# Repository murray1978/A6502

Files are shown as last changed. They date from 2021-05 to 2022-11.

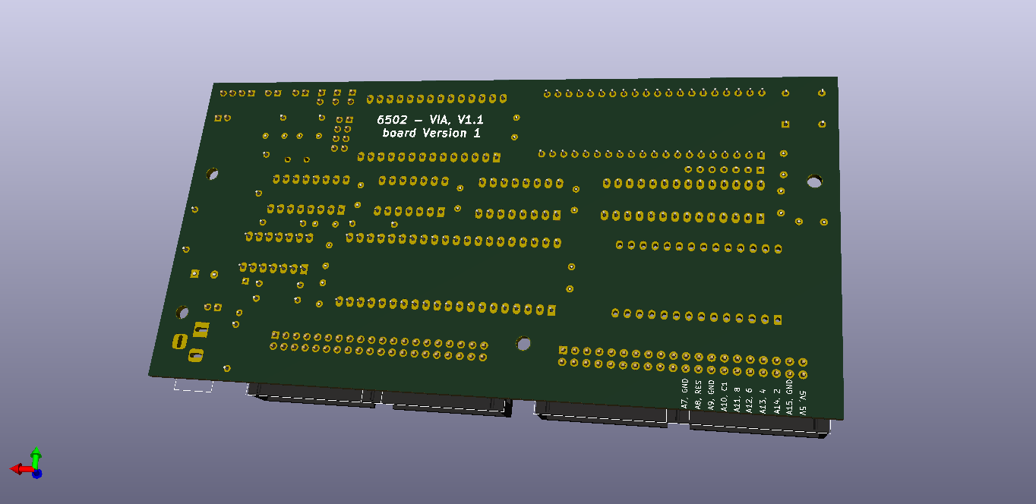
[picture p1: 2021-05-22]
Hardware/6502 V3/6502-Controller1.1.png

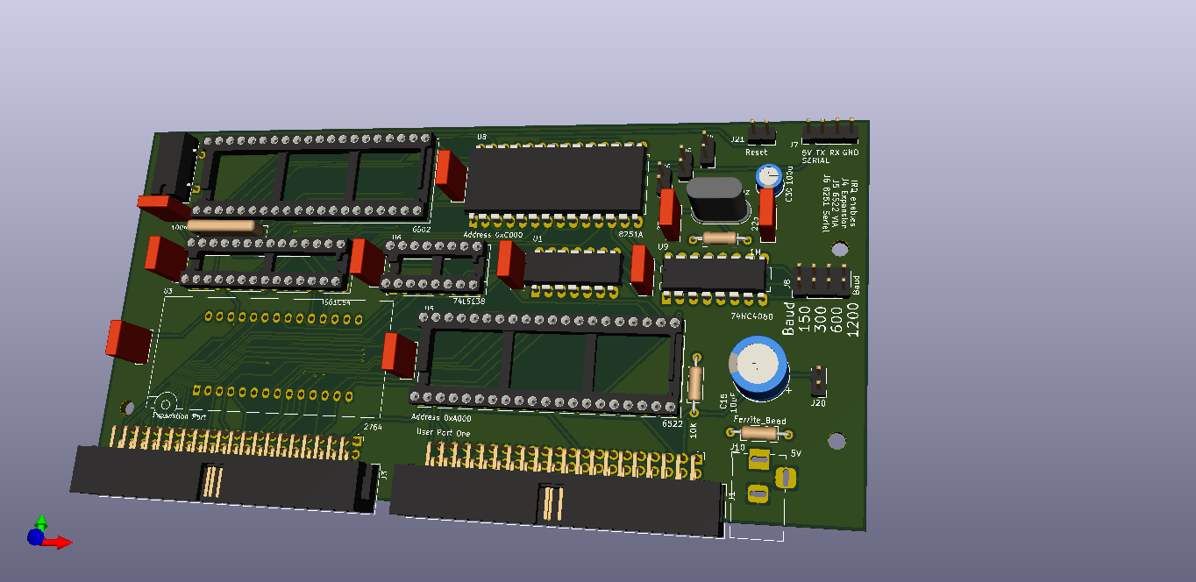
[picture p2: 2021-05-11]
Hardware/6502 V3/6502-Controller.png

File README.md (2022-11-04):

# A6502
- 6502 project running a modified wozmon and wozaci.
- As it stands ram, rom, 8251 interfaces work, yet to try the 6522 interface, the aci or loading basic from the aci.
- ACI will not work unless you remove the rom, make a daughter board for it with 4K of ram, a connector for the ACI 
  and have the rom selected from address 0xF000h, the ram from 0xE000h, and the ACI at the default 0xC000h as the current
  memory decodes the ROM at 0xE000h.
  
 ## version 2 update.
- 11/10/21 Currently the board uses a modified version of EWoz 1.0 (Not uploaded yet)
- 14/8/21 version 2 is included as /hardware/6502/6502-Controller.pro /hardware/6502/6502-Controller.sch and /hardware/6502/6502-Controller.kicad_pcb.
- Fixed an issue with R2 not having a 5V supply, R2 is part of the reset circuit.
- ~The firmware is 6502mon.asm and 6502aci.asm both have yet to be run.
- ~You may have to play around with the 8251a setup for it to work.
### Backplane 
 - Version 1 of the backplane in progress.

 ## Improvements
 - Any improvements and suggestions are welcome

 ## Errors
  ### For the serial to work
   - Select the 150 jumper for 2400 baud, place a jumper between pin 22 and 24 of the 8251, this connects DTR and DSR.
   - Other baud rates should work

 ## Specs
- 6502 processor at 1Mhz
- 8Kb Ram, IS61C64 start 0x0000
- 8Kb Rom, 28C64 start 0xE000
 One user port via a 6522 at 0xA000
 Serial port via a 8251 at 0x8000, baud rates 2400, 1200, 600, and 300
 
 ## Source
 Current source is for the v2.0 board, 
 
 ### Assembling the source
 Currently I am using asm80.com to assemble the code (downloads as a 64k file ) then a hex editor to trim the last 0x2000 bytes (8k)
 And finaly "burning" the eeprom with the 8k image.

 ## Hardware
 Current board is 6502-Controller.kicad_pcb now version 2

 ### Component Selection
 Mostly 74LS, 74HC support chips, 74HCT may also work.

 ## Issues for 6502.1.1.kicad_pcb
 1.  8251A may require a seperate clock if cpu is at 1mhz and programmed at x64 rate.
 2.  No power light 
 3.  Reset could damage older chips, do not use as is. Replace 100u reset cap with 100n cap.
 4.  8251a reset is active high, not low as shown on board.
 5.  74hc4060 incorrect pinout, leading to misleading baud rate signals.

 ## Changes from 6502.1.1.kicad_pcb to 6502-Controller.kicad_pcb
 - ~Add Clock for 8251A, cannot use procssor clock as the 8251A requires a clock atleast 30 times the baud rate. 
 -  CPU clock works with 8251 ok.
 - ~Add LED Power indicator 
 - [x]  Add/Fix missing silk screen text for, user and expasion ports, U4 etc 
 - [x]  Change pinout for RN1, add a pin. 
 -  ~Redesign baud rate generator? make it smaller? Use x1 or x16 for baud rate selection.~
 - [x]  Move bypass caps for ease of extraction tool access. 
 - ~Change values of Baudrate text, reflect 64x clock speed (see issue 5)~
 - ~Reset, change the basic r/c reset to a 555 or inverter based reset, or 100n cap instead of 100u. 
 - [x]  74hc4060 pin out has to be updated, 

## Future additions

 - Basic, looking at adding a basic ROM at 0xA000, 8Kb https://
 - FDC at 0x23F0 (via isa adapter and 82077 FDC controller)
 - An LCD 2x16 Display or CRT monitor.
 
 ## Version 3 idea's
  - Redesign main board as a edge card including address, data and control bus buffers, retaining Serial I/O
  - Have I/O take up a small chunk of memory, from 0xC000 to 0xE000
  - Backplane with 5V PSU
  - Basic in EPROM, bank switched, monitor code moved down to low memory, (BBC Micro like)

## Code Snippets
### Memory Check/count, from MS Basic

        lda     #<RAMSTART2
        ldy     #>RAMSTART2
        sta     LINNUM
        sty     LINNUM+1
        ldy     #$00
L40D7:
        inc     LINNUM
        bne     L40DD
        inc     LINNUM+1
L40DD:
        lda     #$92 ; 10010010 / 00100100
        sta     (LINNUM),y
        cmp     (LINNUM),y
        bne     L40FA
        asl     a
        sta     (LINNUM),y
        cmp     (LINNUM),y
        beq     L40D7; old: faster
        bne     L40FA
L40EE:
        jsr     CHRGOT
        jsr     LINGET
        tay
        beq     L40FA
        jmp     SYNERR
L40FA:

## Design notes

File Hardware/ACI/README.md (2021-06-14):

## Current aci issues.
- eprom footprint wrong.
- bypass caps wrong value, use 100n
- 3.5mm sockets to far from edge.
- text on silkscreen a bit hard to read for some values.
- yet to find any more mistakes.

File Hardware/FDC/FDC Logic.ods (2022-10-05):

 | INPUTS |  |  |  | OUTPUTS
(WD_A0) | (WD_DOR) | (WD_DCR) | (WD_CS)
A0 | A1 | A2 | CS |  | _A0 | _CS | _DOR | _DCR
0 | 0 | 0 | 1 | No Chip Select | 0 | 1 | 1 | 1
0 | 0 | 1 | 0 | DCR Select | 0 | 0 | 1 | 0
0 | 0 | 1 | 1 | No Chip Select | 0 | 1 | 1 | 1
0 | 1 | 0 | 0 | DOR Select | 0 | 0 | 0 | 1
0 | 1 | 0 | 1 | No Chip Select | 0 | 1 | 1 | 1
0 | 1 | 1 | 0 | In Valid | 0 | 1 | 1 | 1
0 | 1 | 1 | 1 | No Chip Select | 0 | 1 | 1 | 1
1 | 0 | 0 | 0 | A0 Select | 1 | 0 | 1 | 1
1 | 0 | 0 | 1 | No Chip Select | 0 | 1 | 1 | 1
1 | 0 | 1 | 0 | In Valid | 0 | 1 | 1 | 1
1 | 0 | 1 | 1 | No Chip Select | 0 | 1 | 1 | 1
1 | 1 | 0 | 0 | In Valid | 0 | 1 | 1 | 1
1 | 1 | 0 | 1 | No Chip Select | 0 | 1 | 1 | 1
1 | 1 | 1 | 0 | InValid | 0 | 1 | 1 | 1
1 | 1 | 1 | 1 | No Chip Select | 0 | 1 | 1 | 1
Notes:
Could use clock

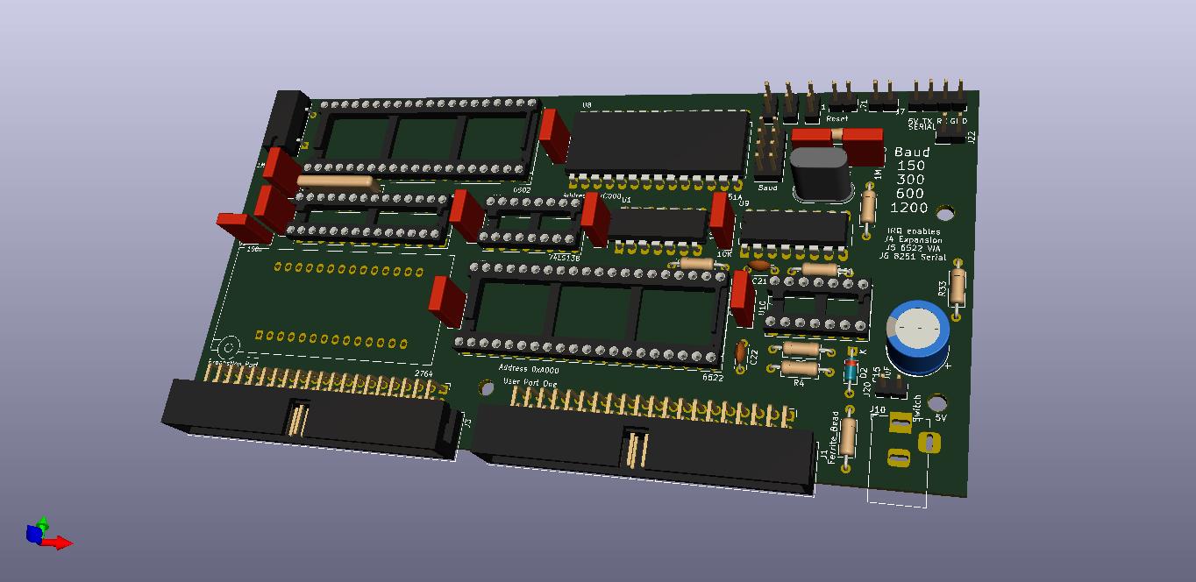
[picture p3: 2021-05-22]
Hardware/6502 V3/6502-Controller1.2.jpg

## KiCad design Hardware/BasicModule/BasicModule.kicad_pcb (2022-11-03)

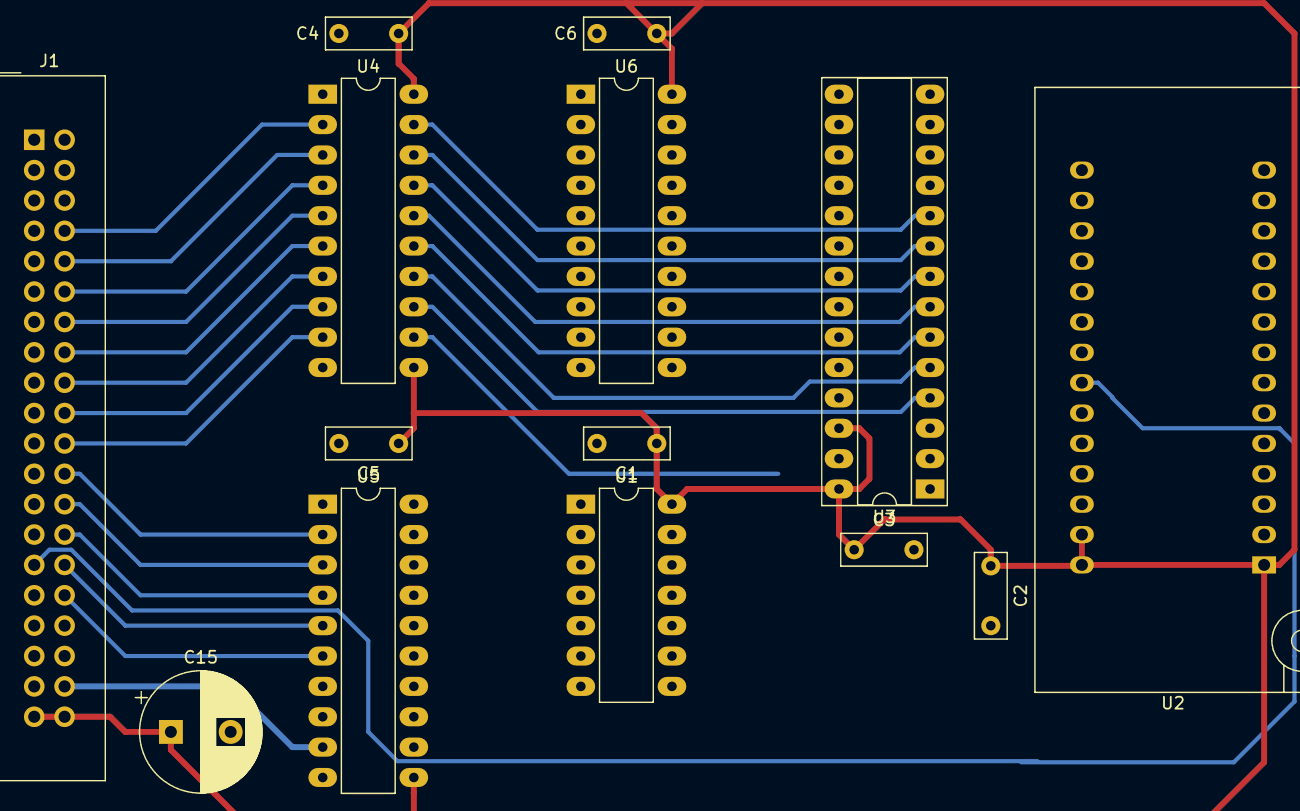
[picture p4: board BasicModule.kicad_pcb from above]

Board: 2 copper layers, 14 parts (0 on the bottom side), 48 nets.

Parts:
C1, C2, C3, C4, C5, C6: 100n; C_Rect_L7.0mm_W2.5mm_P5.00mm
C15: 10uF; CP_Radial_D10.0mm_P5.00mm
J1: Expanstion Port; IDC-Header_2x20_P2.54mm_Vertical
U1: 74LS04; DIP-14_W7.62mm_LongPads
U2: 2764; DIP_Socket-28_W11.9_W12.7_W15.24_W17.78_W18.5_3M_228-1277-0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
U3: IS61C64; DIP-28_W7.62mm_Socket_LongPads
U4, U5: 74LS573; DIP-20_W7.62mm_LongPads
U6: 74LS245; DIP-20_W7.62mm_LongPads

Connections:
0x2000: J1.35, U3.20
0xC000: J1.29, U2.22
5V: C1.1, C2.1, C3.1, C4.1, C5.1, C6.1, C15.1, J1.39, J1.40, U1.14, U2.1, U2.27, U2.28, U3.26, U3.28, U4.11, U4.20, U5.11, U5.20, U6.20
/A0: U2.10, U3.10, U4.19
/A0_1: J1.8, U4.2
/A1: U2.9, U3.9, U4.18
/A1_1: J1.10, U4.3
/A2: U2.8, U3.8, U4.17
/A2_1: J1.12, U4.4
/A3: U2.7, U3.7, U4.16
/A3_1: J1.14, U4.5
/A4: U2.6, U3.6, U4.15
/A4_1: J1.16, U4.6
/A5: U2.5, U3.5, U4.14
/A5_1: J1.18, U4.7
/A6: U2.4, U3.4, U4.13
/A6_1: J1.20, U4.8
/A7: U2.3, U3.3, U4.12
/A7_1: J1.22, U4.9
/A8: U2.25, U3.25, U5.19
/A8_1: J1.24, U5.2
/A9: U2.24, U3.24, U5.18
/A9_1: J1.26, U5.3
/A10: U2.21, U3.21, U5.17
/A10_1: J1.28, U5.4
/A11: U2.23, U3.23, U5.16
/A11_1: J1.30, U5.5
/A12: U2.2, U3.2, U5.15
/A12_1: J1.32, U5.6
/D0: U2.11, U3.11, U6.18
/D0_1: J1.3, U6.2
/D1: U2.12, U3.12, U6.17
/D1_1: J1.5, U6.3
/D2: U2.13, U3.13, U6.16
/D2_1: J1.7, U6.4
/D3: U2.15, U3.15, U6.15
/D3_1: J1.9, U6.5
/D4: U2.16, U3.16, U6.14
/D4_1: J1.11, U6.6
/D5: U2.17, U3.17, U6.13
/D5_1: J1.13, U6.7
/D6: U2.18, U3.18, U6.12
/D6_1: J1.15, U6.8
/D7: U2.19, U3.19, U6.11
/D7_1: J1.17, U6.9
GND: C1.2, C2.2, C3.2, C4.2, C5.2, C6.2, C15.2, J1.1, J1.2, J1.21, J1.25, J1.37, U1.7, U2.14, U2.20, U3.14, U3.22, U4.1, U4.10, U5.1, U5.10, U6.10, U6.19
R~W: J1.19, U1.5, U3.27
~Read: U1.6, U6.1

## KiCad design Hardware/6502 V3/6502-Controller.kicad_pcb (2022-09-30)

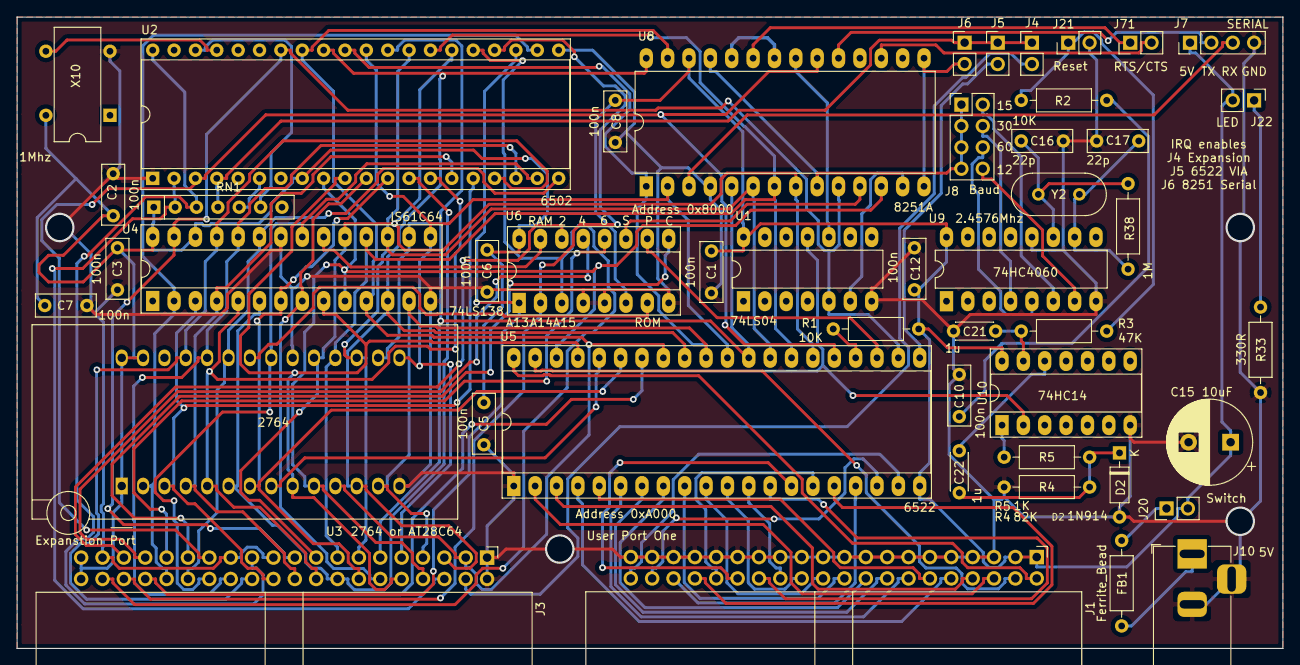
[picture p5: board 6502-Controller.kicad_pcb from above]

Board: 2 copper layers, 150.5 x 75.1 mm, 47 parts (0 on the bottom side), 87 nets.

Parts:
C1, C2, C3, C5, C6, C7, C8, C10, C12: 100n; C_Rect_L7.0mm_W2.5mm_P5.00mm
C15: 10uF; CP_Radial_D10.0mm_P5.00mm
C16, C17: 22p; C_Rect_L7.0mm_W2.5mm_P5.00mm
C21, C22: 1u; C_Disc_D4.3mm_W1.9mm_P5.00mm
D2: 1N914; D_DO-35_SOD27_P7.62mm_Horizontal
FB1: Ferrite_Bead; R_Axial_DIN0207_L6.3mm_D2.5mm_P10.16mm_Horizontal
J1: User Port One; IDC-Header_2x20_P2.54mm_Horizontal
J3: Expanstion Port; IDC-Header_2x20_P2.54mm_Horizontal
J4: Expansion IRQ Enable; PinHeader_1x02_P2.54mm_Vertical
J5: 6522 IRQ Enable; PinHeader_1x02_P2.54mm_Vertical
J6: SERIAL IRQ Enale; PinHeader_1x02_P2.54mm_Vertical
J7: SERIAL; PinHeader_1x04_P2.54mm_Vertical
J8: Baud; PinHeader_2x04_P2.54mm_Vertical
J10: 5V; BarrelJack_Horizontal
J20: Switch; PinHeader_1x02_P2.54mm_Vertical
J21: Reset; PinHeader_1x02_P2.54mm_Vertical
J22: LED; PinHeader_1x02_P2.54mm_Vertical
J71: RTS/CTS; PinHeader_1x02_P2.54mm_Vertical
R1, R2: 10K; R_Axial_DIN0207_L6.3mm_D2.5mm_P10.16mm_Horizontal
R3: 47K; R_Axial_DIN0207_L6.3mm_D2.5mm_P10.16mm_Horizontal
R4: 82K; R_Axial_DIN0207_L6.3mm_D2.5mm_P10.16mm_Horizontal
R5: 1K; R_Axial_DIN0207_L6.3mm_D2.5mm_P10.16mm_Horizontal
R33: 330R; R_Axial_DIN0207_L6.3mm_D2.5mm_P10.16mm_Horizontal
R38: 1M; R_Axial_DIN0207_L6.3mm_D2.5mm_P10.16mm_Horizontal
RN1: 10K; R_Array_SIP7
U1: 74LS04; DIP-14_W7.62mm_LongPads
U2: 6502; DIP-40_W15.24mm_Socket
U3: 2764; DIP_Socket-28_W11.9_W12.7_W15.24_W17.78_W18.5_3M_228-1277-0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
U4: IS61C64; DIP-28_W7.62mm_Socket_LongPads
U5: 6522; DIP-40_W15.24mm_Socket_LongPads
U6: 74LS138; DIP-16_W7.62mm_Socket_LongPads
U8: 8251A; DIP-28_W15.24mm_LongPads
U9: 74HC4060; DIP-16_W7.62mm_LongPads
U10: 74HC14; DIP-14_W7.62mm_Socket_LongPads
X10: SG-531; Oscillator_SeikoEpson_SG-8002DC
Y2: 2.4576Mhz; Crystal_HC49-U_Vertical

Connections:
0x2000: J3.35, U6.14
0x4000: J3.33, U6.13
0x6000: J3.31, U6.12
0xC000: J3.29, U6.9
5V: C1.1, C2.1, C3.1, C5.1, C6.1, C7.1, C8.1, C10.1, C12.1, C15.1, J1.1, J1.3, J3.39, J3.40, J7.1, J20.2, J22.2, R1.2, R2.1, RN1.1, U1.14, U2.8, U3.1, U3.27, U3.28, U4.26, U4.28, U5.20, U6.6, U6.16, U8.26, U9.16, U10.14, X10.8
/A0: J3.8, U2.9, U3.10, U4.10, U5.38, U8.12
/A1: J3.10, U2.10, U3.9, U4.9, U5.37
/A2: J3.12, U2.11, U3.8, U4.8, U5.36
/A3: J3.14, U2.12, U3.7, U4.7, U5.35
/A4: J3.16, U2.13, U3.6, U4.6
/A5: J3.18, U2.14, U3.5, U4.5
/A6: J3.20, U2.15, U3.4, U4.4
/A7: J3.22, U2.16, U3.3, U4.3
/A8: J3.24, U2.17, U3.25, U4.25
/A9: J3.26, U2.18, U3.24, U4.24
/A10: J3.28, U2.19, U3.21, U4.21
/A11: J3.30, U2.20, U3.23, U4.23
/A12: J3.32, U2.22, U3.2, U4.2
/A13: J3.34, U2.23, U6.1
/A14: J3.36, U2.24, U6.2
/A15: J3.38, U2.25, U6.3
/CA1: J1.2, U5.40
/CA2: J1.4, U5.39
/CB1: J1.38, U5.18
/CB2: J1.40, U5.19
/D0: J3.3, U2.33, U3.11, U4.11, U5.33, U8.27
/D1: J3.5, U2.32, U3.12, U4.12, U5.32, U8.28
/D2: J3.7, U2.31, U3.13, U4.13, U5.31, U8.1
/D3: J3.9, U2.30, U3.15, U4.15, U5.30, U8.2
/D4: J3.11, U2.29, U3.16, U4.16, U5.29, U8.5
/D5: J3.13, U2.28, U3.17, U4.17, U5.28, U8.6
/D6: J3.15, U2.27, U3.18, U4.18, U5.27, U8.7
/D7: J3.17, U2.26, U3.19, U4.19, U5.26, U8.8
/PA0: J1.6, U5.2
/PA1: J1.8, U5.3
/PA2: J1.10, U5.4
/PA3: J1.12, U5.5
/PA4: J1.14, U5.6
/PA5: J1.16, U5.7
/PA6: J1.18, U5.8
/PA7: J1.20, U5.9
/PB0: J1.22, U5.10
/PB1: J1.24, U5.11
/PB2: J1.26, U5.12
/PB3: J1.28, U5.13
/PB4: J1.30, U5.14
/PB5: J1.32, U5.15
/PB6: J1.34, U5.16
/PB7: J1.36, U5.17
B150: J8.2, U9.6
B300: J8.4, U9.4
B600: J8.6, U9.5
B1200: J8.8, U9.7
CLK0: U2.37, X10.5
CLK1: J3.27, U2.3, U5.25, U8.20
GND: C1.2, C2.2, C3.2, C5.2, C6.2, C7.2, C8.2, C10.2, C12.2, C15.2, C16.2, C17.2, C21.2, D2.2, J1.5, J1.7, J1.9, J1.11, J1.13, J1.15, J1.17, J1.19, J1.21, J1.23, J1.25, J1.27, J1.29, J1.31, J1.33, J1.35, J1.37, J1.39, J3.1, J3.2, J3.21, J3.25, J3.37, J7.4, J10.2, J10.3, J21.2, R4.2, R33.1, U1.7, U2.1, U2.21, U3.14, U3.20, U4.14, U4.22, U5.1, U6.4, U6.5, U6.8, U8.4, U9.8, U9.12, U10.7, X10.4
unnamed: C16.1, R38.2, U9.11, Y2.1
unnamed: C17.1, R38.1, U9.10, Y2.2
unnamed: C21.1, R3.2, U10.13
unnamed: C22.1, U10.12
unnamed: C22.2, D2.1, R4.1, R5.1
unnamed: FB1.1, J20.1
unnamed: FB1.2, J10.1
unnamed: J3.4, J4.2
unnamed: J5.2, U5.21
unnamed: J6.2, U8.14, U8.15
unnamed: J7.2, U8.19
unnamed: J7.3, U8.3
unnamed: J8.1, J8.3, J8.5, J8.7, U8.9, U8.25
unnamed: J21.1, R2.2, R3.1
unnamed: J22.1, R33.2
unnamed: J71.1, U8.23
unnamed: J71.2, U8.17
unnamed: R1.1, U5.24
unnamed: R5.2, U10.1
unnamed: RN1.5, U2.6
unnamed: RN1.6, U2.38
unnamed: U1.10, U8.21
RDY: J3.6, RN1.2, U2.2
R~W: J3.19, U1.5, U2.34, U4.27, U5.22, U8.10
~6522_EN: U5.23, U6.10
~8251_EN: U6.11, U8.11
~IRQ: J4.1, J5.1, J6.1, RN1.4, U2.4
~RAM_EN: U4.20, U6.15
~RES: J3.23, RN1.3, U1.11, U2.40, U5.34, U10.2
~ROM_EN: U3.22, U6.7
~Read: U1.6, U8.13

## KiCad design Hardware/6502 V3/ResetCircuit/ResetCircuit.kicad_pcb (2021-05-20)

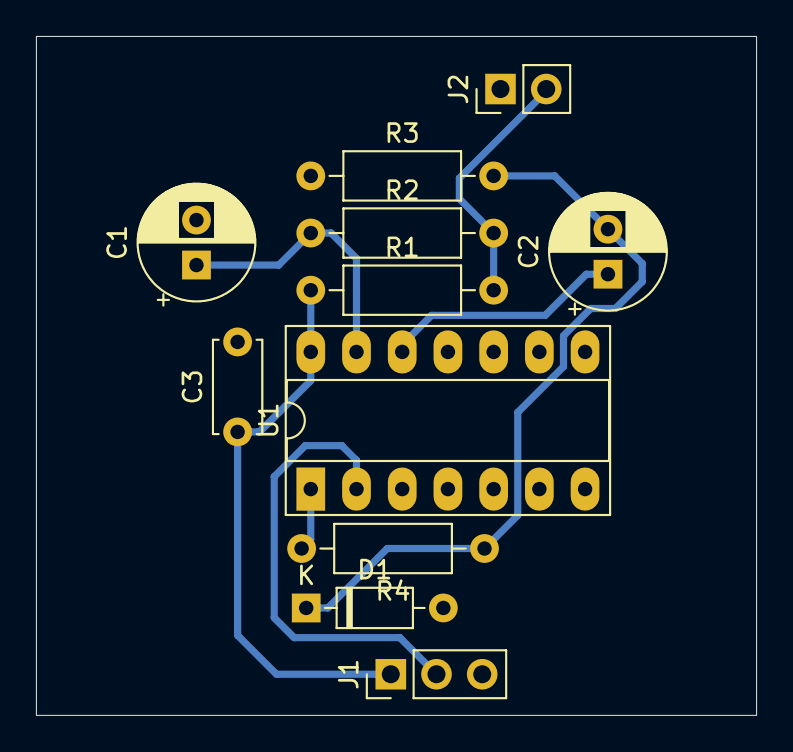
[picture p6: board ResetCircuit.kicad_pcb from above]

Board: 2 copper layers, 40.0 x 37.7 mm, 11 parts (0 on the bottom side), 8 nets.

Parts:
C1, C2: 1uf; CP_Radial_D6.3mm_P2.50mm
C3: 100n; C_Disc_D5.0mm_W2.5mm_P5.00mm
D1: 1N914; D_DO-35_SOD27_P7.62mm_Horizontal
J1: ~Reset; PinHeader_1x03_P2.54mm_Vertical
J2: Switch; PinHeader_1x02_P2.54mm_Vertical
R1: 10k; R_Axial_DIN0207_L6.3mm_D2.5mm_P10.16mm_Horizontal
R2: 47K; R_Axial_DIN0207_L6.3mm_D2.5mm_P10.16mm_Horizontal
R3: 82K; R_Axial_DIN0207_L6.3mm_D2.5mm_P10.16mm_Horizontal
R4: 1K; R_Axial_DIN0207_L6.3mm_D2.5mm_P10.16mm_Horizontal
U1: 74HC14; DIP-14_W7.62mm_Socket_LongPads

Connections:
/5V: C3.1, J1.1, R1.1, U1.14
/GND: C1.2, C3.2, D1.2, J1.3, J2.1, R3.1, U1.7
unnamed: C1.1, R2.1, U1.13
unnamed: C2.1, U1.12
unnamed: C2.2, D1.1, R3.2, R4.1
unnamed: J1.2, U1.2
unnamed: J2.2, R1.2, R2.2
unnamed: R4.2, U1.1

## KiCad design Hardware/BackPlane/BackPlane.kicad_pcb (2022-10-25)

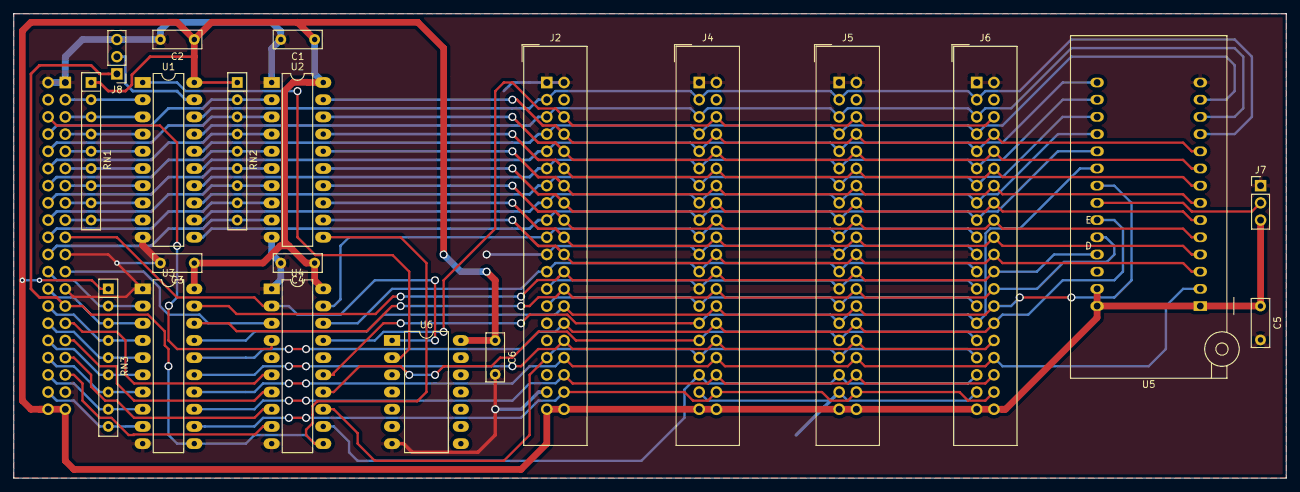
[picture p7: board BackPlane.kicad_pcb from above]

Board: 2 copper layers, 188.0 x 68.6 mm, 22 parts (1 on the bottom side), 69 nets.

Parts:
C1, C2, C3, C4, C5, C6: 100n; C_Rect_L7.0mm_W2.5mm_P5.00mm
J1: TO A6502; IDC-Header_2x20_P2.54mm_Horizontal
J2: Video; IDC-Header_2x20_P2.54mm_Vertical
J4: FDC; IDC-Header_2x20_P2.54mm_Vertical
J5: EX1; IDC-Header_2x20_P2.54mm_Vertical
J6: EX2; IDC-Header_2x20_P2.54mm_Vertical
J7: User Rom Enable; PinHeader_1x03_P2.54mm_Vertical
J8: DB Enable select; PinHeader_1x03_P2.54mm_Vertical
RN1, RN2, RN3: R_Network08; R_Array_SIP9
U1: 74LS245; DIP-20_W7.62mm_LongPads
U2, U3, U4: 74LS573; DIP-20_W7.62mm_LongPads
U5: 2764; DIP_Socket-28_W11.9_W12.7_W15.24_W17.78_W18.5_3M_228-1277-0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
U6: 74LS04; DIP-14_W10.16mm_LongPads

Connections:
5V: C1.1, C2.1, C3.1, C4.1, C5.1, C6.1, J1.39, J1.40, J2.39, J2.40, J4.39, J4.40, J5.39, J5.40, J6.39, J6.40, J7.3, RN1.1, RN2.1, RN3.1, U1.20, U2.20, U3.20, U4.20, U5.1, U5.27, U5.28, U6.14
/2000: J4.35, J5.35, J6.35, U4.12
/4000: J2.33, J4.33, J5.33, J6.33, U4.13
/6000: J4.31, J5.31, J6.31, U4.14
/A0: J2.8, J4.8, J5.8, J6.8, U2.19, U5.10
/A1: J2.10, J4.10, J5.10, J6.10, U2.18, U5.9
/A2: J2.12, J4.12, J5.12, J6.12, U2.17, U5.8
/A3: J2.14, J4.14, J5.14, J6.14, U2.16, U5.7
/A4: J2.16, J4.16, J5.16, J6.16, U2.15, U5.6
/A5: J2.18, J4.18, J5.18, J6.18, U2.14, U5.5
/A6: J2.20, J4.20, J5.20, J6.20, U2.13, U5.4
/A7: J2.22, J4.22, J5.22, J6.22, U2.12, U5.3
/A8: J2.24, J4.24, J5.24, J6.24, U3.19, U5.25
/A9: J2.26, J4.26, J5.26, J6.26, U3.18, U5.24
/A10: J2.28, J4.28, J5.28, J6.28, U3.17, U5.21
/A11: J2.30, J4.30, J5.30, J6.30, U3.16, U5.23
/A12: J2.32, J4.32, J5.32, J6.32, U3.15
/A13: J2.34, J4.34, J5.34, J6.34, U3.14, U5.2
/A14: J2.36, J4.36, J5.36, J6.36, U3.13
/A15: J2.38, J4.38, J5.38, J6.38, U3.12
/C000: J4.29, J5.29, J6.29, U4.15, U5.20
/CLK: J2.27, J4.27, J5.27, J6.27
/D0: J2.3, J4.3, J5.3, J6.3, U1.18, U5.11
/D1: J2.5, J4.5, J5.5, J6.5, U1.17, U5.12
/D2: J2.7, J4.7, J5.7, J6.7, U1.16, U5.13
/D3: J2.9, J4.9, J5.9, J6.9, U1.15, U5.15
/D4: J2.11, J4.11, J5.11, J6.11, U1.14, U5.16
/D5: J2.13, J4.13, J5.13, J6.13, U1.13, U5.17
/D6: J2.15, J4.15, J5.15, J6.15, U1.12, U5.18
/D7: J2.17, J4.17, J5.17, J6.17, U1.11, U5.19
/RDY: J2.6, J4.6, J5.6, J6.6, U4.17
/R~W: J2.19, J4.19, J5.19, J6.19, U4.19
/_2000: J1.35, U4.9
/_4000: J1.33, U4.8
/_6000: J1.31, U4.7
/_A0: J1.8, RN2.2, U2.2
/_A1: J1.10, RN2.3, U2.3
/_A2: J1.12, RN2.4, U2.4
/_A3: J1.14, RN2.5, U2.5
/_A4: J1.16, RN2.6, U2.6
/_A5: J1.18, RN2.7, U2.7
/_A6: J1.20, RN2.8, U2.8
/_A7: J1.22, RN2.9, U2.9
/_A8: J1.24, RN3.2, U3.2
/_A9: J1.26, RN3.3, U3.3
/_A10: J1.28, RN3.4, U3.4
/_A11: J1.30, RN3.5, U3.5
/_A12: J1.32, RN3.6, U3.6
/_A13: J1.34, RN3.7, U3.7
/_A14: J1.36, RN3.8, U3.8
/_A15: J1.38, RN3.9, U3.9
/_C000: J1.29, U4.6
/_CLK: J1.27, J8.1, U2.11, U3.11, U4.11
/_D0: J1.3, RN1.2, U1.2
/_D1: J1.5, RN1.3, U1.3
/_D2: J1.7, RN1.4, U1.4
/_D3: J1.9, RN1.5, U1.5
/_D4: J1.11, RN1.6, U1.6
/_D5: J1.13, RN1.7, U1.7
/_D6: J1.15, RN1.8, U1.8
/_D7: J1.17, RN1.9, U1.9
/_RDY: J1.6, U4.4
/_R~W: J1.19, U4.2, U6.1
/_~RESET: J1.23, U4.3
/~RESET: J2.23, J4.23, J5.23, J6.23, U4.18
GND: C1.2, C2.2, C3.2, C4.2, C5.2, C6.2, J1.1, J1.2, J1.21, J1.25, J1.37, J2.1, J2.2, J2.21, J2.25, J2.37, J4.1, J4.2, J4.21, J4.25, J4.37, J5.1, J5.2, J5.21, J5.25, J5.37, J6.1, J6.2, J6.21, J6.25, J6.37, J7.1, J8.3, U1.10, U2.1, U2.10, U3.1, U3.10, U4.1, U4.10, U5.14, U6.7
unnamed: J7.2, U5.22
unnamed: J8.2, U1.19
unnamed: U1.1, U6.2

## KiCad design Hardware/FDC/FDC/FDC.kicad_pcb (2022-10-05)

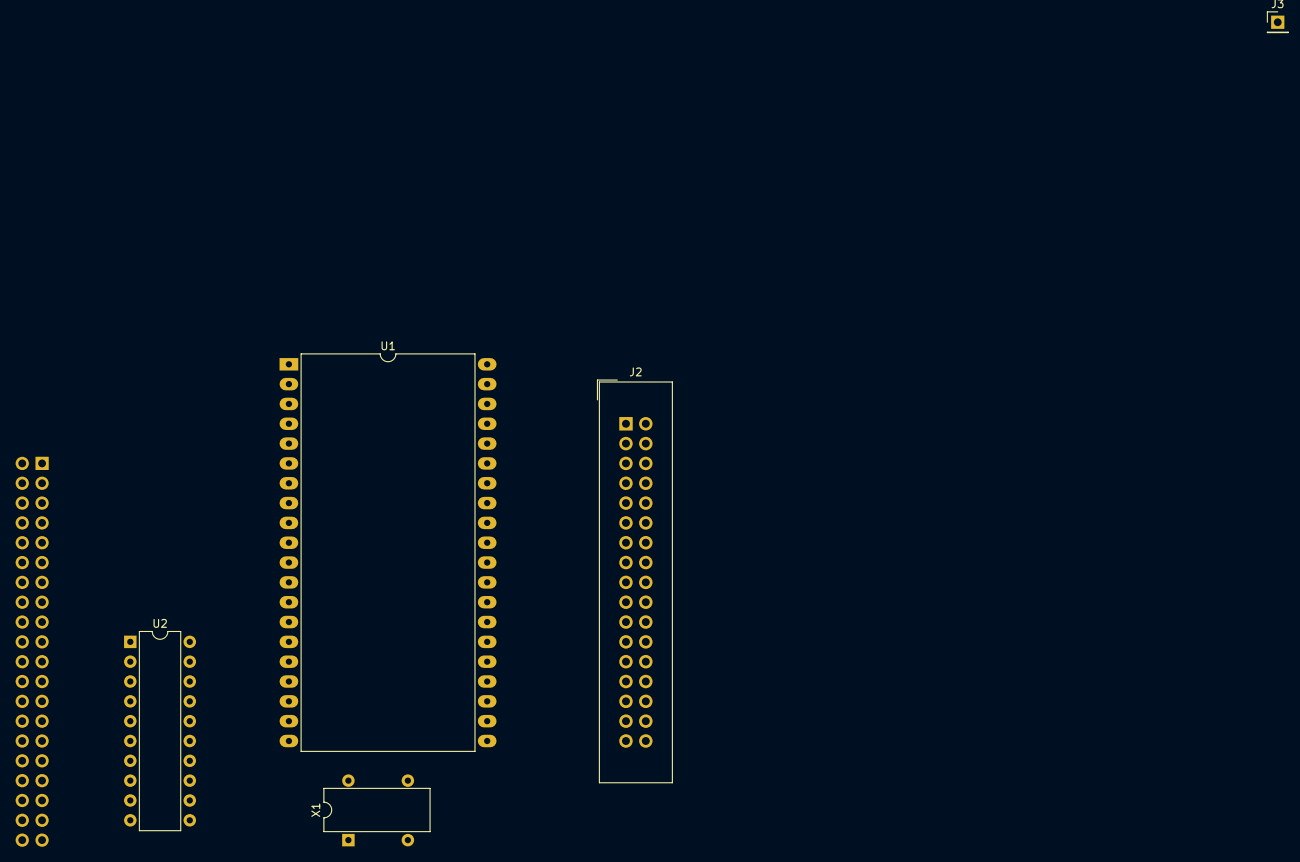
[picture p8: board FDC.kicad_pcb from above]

Board: 2 copper layers, 6 parts (1 on the bottom side), 41 nets, no tracks yet.

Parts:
J1: FDC_Backplane; PinHeader_2x20_P2.54mm_Horizontal
J2: FDC; IDC-Header_2x17_P2.54mm_Vertical
J3: Conn_01x01; PinHeader_1x01_P2.54mm_Vertical
U1: WD37C65C; DIP-40_W25.4mm_LongPads
U2: GAL16V8; DIP-20_W7.62mm
X1: SG-531; Oscillator_SeikoEpson_SG-8002DC

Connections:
5V: J1.39, J1.40, U1.24, U1.40, U2.20, X1.1, X1.8
/2000: J1.35, U2.5
/A0: J1.8, U2.2
/A1: J1.10, U2.3
/A2: J1.12, U2.4
/CLK: J1.27, U2.1
/D0: J1.3, U1.7
/D1: J1.5, U1.8
/D2: J1.7, U1.9
/D3: J1.9, U1.10
/D4: J1.11, U1.11
/D5: J1.13, U1.12
/D6: J1.15, U1.13
/D7: J1.17, U1.14
/DEN_SEL: J2.2, U1.36
/DSA: J2.14, U1.30
/DSB: J2.12, U1.32
/MOTEA: J2.10, U1.33
/R~W: J1.19, U2.7
/WDATA: J2.22, U1.27
/~DC: J2.34, J3.1
/~DIR: J2.18, U1.28
/~IDX: J2.8, U1.39
/~INT: J1.4, U1.16
/~MOTEB: J2.16, U1.34
/~RDATA: J2.30, U1.20
/~RESET: J1.23, U2.6
/~SIDE: J2.32, U1.25
/~STWP: J2.20, U1.29
/~TR0: J2.26, U1.38
/~WGATE: J2.24, U1.26
/~WP: J2.28, U1.37
GND: J1.1, J1.2, J1.21, J1.25, J1.37, J2.1, J2.3, J2.5, J2.7, J2.9, J2.11, J2.13, J2.15, J2.17, J2.19, J2.21, J2.23, J2.25, J2.27, J2.29, J2.31, J2.33, U1.21, U1.22, U1.31, U2.10, X1.4
unnamed: U1.1, U2.19
unnamed: U1.2, U2.18
unnamed: U1.3, U2.16
unnamed: U1.4, U2.17
unnamed: U1.17, U2.15
unnamed: U1.18, U2.14
unnamed: U1.19, U2.13
unnamed: U1.23, X1.5

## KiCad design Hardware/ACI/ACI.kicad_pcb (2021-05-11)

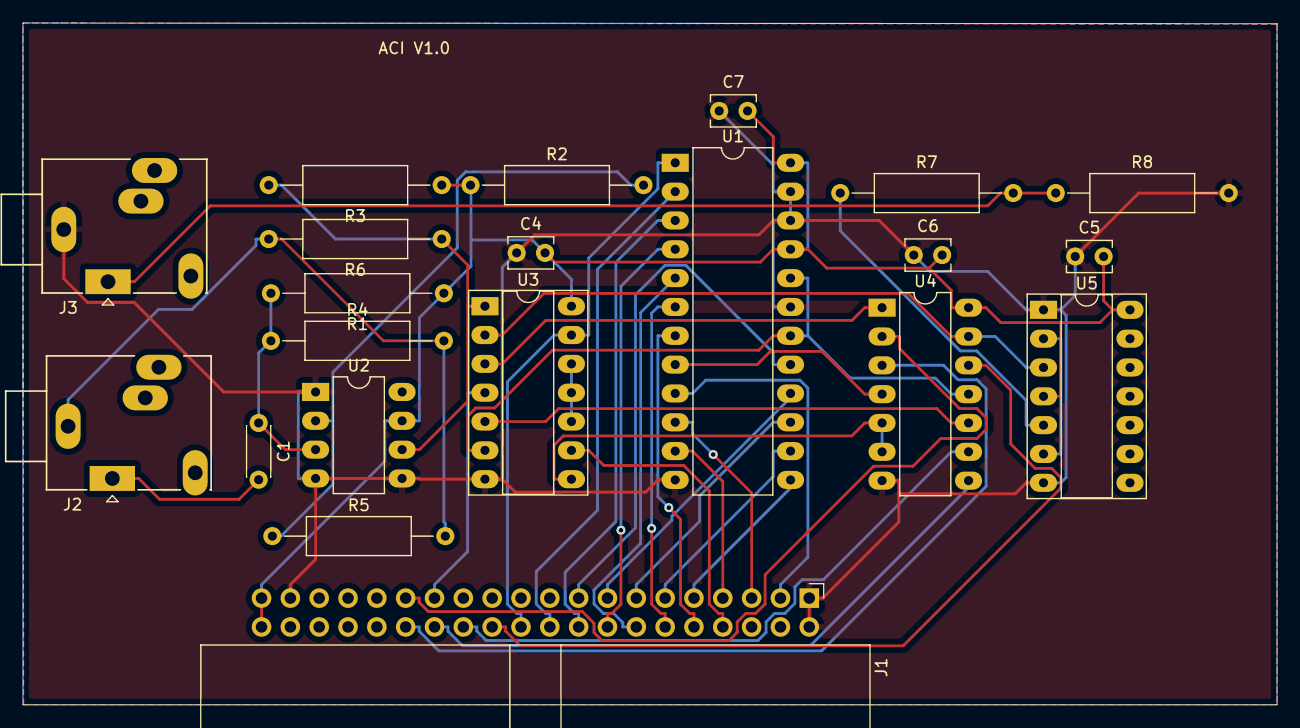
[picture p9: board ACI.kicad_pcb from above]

Board: 2 copper layers, 110.5 x 60.1 mm, 21 parts (0 on the bottom side), 39 nets.

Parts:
C1: 10n; C_Disc_D4.3mm_W1.9mm_P5.00mm
C4, C5, C6, C7: 10n; C_Disc_D3.8mm_W2.6mm_P2.50mm
J1: SystemBus; IDC-Header_2x20_P2.54mm_Horizontal
J2: From Tape; Jack_3.5mm_Ledino_KB3SPRS_Horizontal
J3: To Tape; Jack_3.5mm_Ledino_KB3SPRS_Horizontal
R1, R2, R4, R5, R7: 10K; R_Axial_DIN0309_L9.0mm_D3.2mm_P15.24mm_Horizontal
R3: 3K; R_Axial_DIN0309_L9.0mm_D3.2mm_P15.24mm_Horizontal
R6: 47K; R_Axial_DIN0309_L9.0mm_D3.2mm_P15.24mm_Horizontal
R8: 10R; R_Axial_DIN0309_L9.0mm_D3.2mm_P15.24mm_Horizontal
U1: AT28C16; DIP-24_W10.16mm_LongPads
U2: LM741; DIP-8_W7.62mm_LongPads
U3: 74LS10; DIP-14_W7.62mm_Socket_LongPads
U4: 74LS02; DIP-14_W7.62mm_LongPads
U5: 74LS74; DIP-14_W7.62mm_Socket_LongPads

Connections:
5V: C4.2, C5.2, C6.2, C7.2, J1.39, J1.40, R1.1, R2.1, R3.1, U1.21, U1.24, U2.7, U3.14, U4.14, U5.4, U5.14
/A1: J1.10, U1.7
/A2: J1.12, U1.6
/A3: J1.14, U1.5
/A4: J1.16, U1.4
/A5: J1.18, U1.3
/A6: J1.20, U1.2
/A7: J1.22, U1.1, U3.13
/A8: J1.24, U4.12
/A9: J1.26, U4.9
/A10: J1.28, U4.8
/A11: J1.30, U4.3
/D0: J1.3, U1.9
/D1: J1.5, U1.10
/D2: J1.7, U1.11
/D3: J1.9, U1.13
/D4: J1.11, U1.14
/D5: J1.13, U1.15
/D6: J1.15, U1.16
/D7: J1.17, U1.17
A0: J1.8, U3.9
A00: U1.8, U4.4
AUDIO_OUT: R3.2, R6.1, U2.6, U3.1
CLK1: J1.27, U3.4
GND: C4.1, C5.1, C6.1, C7.1, J1.1, J1.2, J1.37, J3.S, R8.2, U1.12, U1.19, U1.22, U1.23, U2.1, U2.4, U2.5, U3.7, U4.7, U5.1, U5.7
unnamed: C1.1, R1.2, R4.1, U2.3
unnamed: C1.2, J2.T
unnamed: J2.S, R4.2, R5.2, R6.2
unnamed: J3.T, R7.2, R8.1
unnamed: R2.2, R5.1, U2.2
unnamed: R7.1, U5.5
unnamed: U3.2, U4.13, U5.3
unnamed: U3.3, U4.1
unnamed: U3.5, U4.10
unnamed: U3.8, U4.5, U4.6
unnamed: U3.10, U3.11, U3.12
unnamed: U5.2, U5.6
~4KCS: J1.29, U4.2
~CS: U1.18, U1.20, U3.6, U4.11

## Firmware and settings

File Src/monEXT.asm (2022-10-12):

; EWOZ Extended Woz Monitor.
; Just a few mods to the original monitor.

; START @ $E000
            ORG $E000

;FDC routines
FDC_BASE 		EQU		$2000		;
FDC_CONTROL     EQU     FDC_BASE
FDC_DATA        EQU     FDC_BASE+1
FDC_DOR         EQU     FDC_BASE+$02
FDC_DCR         EQU     FDC_BASE+$04


FDC_BUFFER      EQU     $0400
FDC_BUFFER_END  EQU     FDC_BUFFER_END + $0200      
FDC_BUFFER_PTR  EQU     40

;Init FDC @ 0x6000
FDC_INIT		RTS
FDC_READ		RTS
FDC_WRITE		RTS
FDC_STATUS		RTS

;VDU
VDU_BASE		EQU		$4000		;4K VDU Ram 0x4000

;6522 VIA Testing, call with E100R
VIA_BASE		EQU 	$A000		;6522 VIA base
VIA_REGB		EQU		VIA_BASE
VIA_REGA		EQU		VIA_BASE + 1
VIA_DDRB		EQU		VIA_BASE + 2
VIA_DDRA		EQU		VIA_BASE + 3
				ORG 	$E100
;Setup VIA
VIA_INIT		LDA $FF
				STA	VIA_DDRA
LEDLOOP			LDA $FF					;turn LED on
				STA VIA_REGB
				JSR DELAY
				LDA $00					;Turn LED off
				STA VIA_REGB
				JSR DELAY
				JMP LEDLOOP
        
DELAY 		  	LDX $FF
				DEX
				CPX #00
				BNE DELAY
DELAY2  		LDX $FF
				DEX
				CPX #00 
				BNE DELAY2
				RTS  

IN          EQU $0200          ;*Input buffer
XAML        EQU $24            ;*Index pointers
XAMH        EQU $25
STL         EQU $26
STH         EQU $27
L           EQU $28
H           EQU $29
YSAV        EQU $2A
MODE        EQU $2B
MSGL        EQU $2C
MSGH        EQU $2D
COUNTER     EQU $2E
CRC         EQU $2F
CRCCHECK    EQU $30


; We are not using a 6520 or a Terminal but a 8251A at 0xC000 
SERIAL_DATA     EQU     $8000           ;8251 Data Address
SERIAL_CMD      EQU     SERIAL_DATA+1   ;8251 Cmd Address
RST_CMD         EQU     $40             ;Reset Command sent 4 times
MODE_CMD        EQU     %01001111       ;Async mode, 8,n,1, 64x rate
DATA_CMD        EQU     %00010101       ;RTS/CTS DSR/DTR off
RX_READY        EQU     $02             ;8251 ready to recive

RESET:          CLD                     ;Clear decimal arithmetic mode
                SEI                     ;Disable interupts
                LDX     $FF             ;Stack Address in page 1
                TXS                     ;And set stack address
                LDA     #$00            ;Start with a reset
                STA     SERIAL_CMD
                STA     SERIAL_CMD
                STA     SERIAL_CMD
                STA     SERIAL_CMD
                LDA     #RST_CMD         ;Should be able to reset device here
                STA     SERIAL_CMD
                LDA     #MODE_CMD    
                STA     SERIAL_CMD      
                LDA     #DATA_CMD
                STA     SERIAL_CMD 
         LDA #$0D
         JSR ECHO      ;* New line.
         LDA #<MSG1
         STA MSGL
         LDA #>MSG1
         STA MSGH
         JSR SHWMSG      ;* Show Welcome.
         LDA #$0D
         JSR ECHO      ;* New line.
SOFTRESET:   LDA #$9B      ;* Auto escape.
NOTCR:       CMP #$88        ;"<-"? * Note this was chaged to $88 which is the back space key.
            BEQ BACKSPACE   ;Yes.
            CMP #$9B        ;ESC?
            BEQ ESCAPE      ;Yes.
            INY             ;Advance text index.
            BPL NEXTCHAR    ;Auto ESC if >127.
ESCAPE:      LDA #$DC        ;"\"
            JSR ECHO        ;Output it.
GETLINE:     LDA #$8D        ;CR.
            JSR ECHO        ;Output it.
            LDY #$01        ;Initiallize text index.
BACKSPACE:   DEY             ;Backup text index.
            BMI GETLINE     ;Beyond start of line, reinitialize.
         LDA #$A0      ;*Space, overwrite the backspaced char.
         JSR ECHO
         LDA #$88      ;*Backspace again to get to correct pos.
         JSR ECHO
NEXTCHAR:    LDA     SERIAL_CMD      ;Wait for key press
            AND     #RX_READY
            BEQ     NEXTCHAR        ;No key yet!
            LDA     SERIAL_DATA
         CMP #$60      ;*Is it Lower case
         BMI   CONVERT      ;*Nope, just convert it
         AND #$5F      ;*If lower case, convert to Upper case
CONVERT:     ORA #$80        ;*Convert it to "ASCII Keyboard" Input
            STA IN,Y        ;Add to text buffer.
            JSR ECHO        ;Display character.
            CMP #$8D        ;CR?
            BNE NOTCR       ;No.
            LDY #$FF        ;Reset text index.
            LDA #$00        ;For XAM mode.
            TAX             ;0->X.
SETSTOR:     ASL             ;Leaves $7B if setting STOR mode.
SETMODE:     STA MODE        ;$00 = XAM, $7B = STOR, $AE = BLOK XAM.
BLSKIP:      INY             ;Advance text index.
NEXTITEM:    LDA IN,Y        ;Get character.
            CMP #$8D        ;CR?
            BEQ GETLINE     ;Yes, done this line.
            CMP #$AE        ;"."?
            BCC BLSKIP      ;Skip delimiter.
            BEQ SETMODE     ;Set BLOCK XAM mode.
            CMP #$BA        ;":"?
            BEQ SETSTOR     ;Yes, set STOR mode.
         CMP #$D2        ;"R"?
            BEQ RUN         ;Yes, run user program.
            CMP #$CC        ;* "L"?
            BEQ LOADINT     ;* Yes, Load Intel Code.
            STX L           ;$00->L.
            STX H           ; and H.
            STY YSAV        ;Save Y for comparison.
NEXTHEX:     LDA IN,Y        ;Get character for hex test.
            EOR #$B0        ;Map digits to $0-9.
            CMP #$0A        ;Digit?
            BCC DIG         ;Yes.
            ADC #$88        ;Map letter "A"-"F" to $FA-FF.
            CMP #$FA        ;Hex letter?
            BCC NOTHEX      ;No, character not hex.
DIG:         ASL
            ASL             ;Hex digit to MSD of A.
            ASL
            ASL
            LDX #$04        ;Shift count.
HEXSHIFT:    ASL             ;Hex digit left MSB to carry.
            ROL L           ;Rotate into LSD.
            ROL H           ;Rotate into MSD's.
            DEX             ;Done 4 shifts?
            BNE HEXSHIFT    ;No, loop.
            INY             ;Advance text index.
            BNE NEXTHEX     ;Always taken. Check next character for hex.
NOTHEX:      CPY YSAV        ;Check if L, H empty (no hex digits).
         BNE NOESCAPE   ;* Branch out of range, had to improvise...
            JMP ESCAPE      ;Yes, generate ESC sequence.

RUN:         JSR ACTRUN      ;* JSR to the Address we want to run.
         JMP   SOFTRESET   ;* When returned for the program, reset EWOZ.
ACTRUN:      JMP (XAML)      ;Run at current XAM index.

LOADINT:      JSR LOADINTEL   ;* Load the Intel code.
         JMP   SOFTRESET   ;* When returned from the program, reset EWOZ.
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

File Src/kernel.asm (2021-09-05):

;6502 Kernel
ORG	$E000	;4K ROM Start

;Data Defines
MSG_START DW #"Kernal 1",$00	;Null terminate

;Memory Locations

	;Delay - place delay values into these locations then call subroutine
	DELAY_5US		EQU 	$20
	DELAY_1248US	EQU		$21
	
	;MOVE256
	MOV256_S_L	  	EQU	   	$40	;Source Low					
	MOV256_S_H		EQU		$41	;Source High	
	MOV256_D_L	  	EQU		$42	;Destination Low			
	MOV256_D_H	  	EQU		$43	;Destination High	
	MOV256_COUNT  	EQU		$44	;Number of bytes to move	
	
	;Input
	key_buff_s  	EQU		#$F0	;Key buffer size in bytes, 80 characters,
	key_buff_l  	EQU		$0200	;Number of items in keybuffer
	key_buff_b  	EQU		$0201	;Beginning of current key in buffer (to be retrieved
	key_buff_e		EQU		$0202	;Key Buffer end where, serin places key
	key_buff_f  	EQU		$0203	;stores current status, flags - full, empty, eol
	key_buff		EQU		$0204	;Key buffer location
	
	out_buf_s		EQU		#$F0	;output buffer size in bytes, 80 Characters
	
	;Task Swicthing location data
	TEMP_ACC	EQU	$0300
	TEMP_X		EQU $0301
	TEMP_Y		EQU $0302
	TEMP_STATUS EQU $0303
	TEMP_PC_H   EQU $0304
	TEMP_PC_L   EQU $0305
	STACK_P		EQU $0306
	TASKLIST_S  EQU $0310	;Task List start
	
	;FDC
	FDC_ROM			EQU 	$2000
	FDC_BUFFER		EQU		$3000
	FDC_BUFFER_S	EQU		$0FFF
	
;==========================================================================================================================
;Move256 Moves up to 256 bytes of data from to locations
MOVE256			PHP					;Save Processor	status		
				PHA					;Save Accumulator
				TXA					;Save X
				PHA					;
				TYA					;Save Y
				PHA
				LDX	MOV256_COUNT	;$44
				SEC
				LDA MOV256_D_L		;$42
				SBC MOV256_S_L		;$40
				LDA MOV256_D_H		;$43
				SBC MOV256_S_H		;$41
				BMI MOV256_DSPN		;Displacement negitive
				LDY MOV256_COUNT
MOV256_CONT1 	DEY
				LDA (MOV256_S_L),Y
				STA (MOV256_D_L),Y
				DEX
				BNE MOV256_CONT1
				RTS
MOV256_DSPN		LDY #00
MOV256_CONT2	LDA (MOV256_S_L),y
				STA (MOV256_D_L),Y
				INY
				DEX
				BNE MOV256_CONT2
				PLA			;Restore y
				TAY
				PLA			;Restore X
				TAX
				PLA			;Restore Accumulator
				PLP
				RTS			;restore processor status
;====================================== END Move256 =======================================================================

;====================================== Delay =============================================================================
DELAY1			
				PHP			;Save Processor			;Stored nomally during call, but not for jmp.
				PHA			;Save Accumulator
				TXA			;Save X
				PHA			;
				TYA			;Save Y
				PHA
				LDX	DELAY_5US
				LDY	DELAY_1248US
DELAY1_WAIT		DEX	
				BNE	DELAY1_WAIT
				DEY
				BNE	DELAY1_WAIT
				PLA			;Restore y
				TAY
				PLA			;Restore X
				TAX
				PLA			;Restore Accumulator
				PLP
				RTS
;Example task list
	;name 	= 8 bytes
	;PC	  	= 2 Bytes
	;status = 1 byte
	;reg.a  = 1 byte
	;reg.x  = 1 byte
	;reg.y  = 1 byte
	;reg.stack = 1 byte
	;reg.stack_p = 1 byte
	
;For task switching
	;JSR	- Jump to subroutine
	; Stack has stack.top -> 	??
	;							PC.h,
	;							PC.l
	
;Save Registers
	PHP			;Save Processor			;Stored nomally during call, but not for jmp.
	PHA			;Save Accumulator
	TXA			;Save X
	PHA			;
	TYA			;Save Y
	PHA
;Restore registers
	PLA			;Restore y
	TAY
	PLA			;Restore X
	TAX
	PLA			;Restore Accumulator
	PLP

;========================================== IRQ handlers ====================================================================
IDLE_IRQ RTI			;Idle task switching handler
NMI_IRQ  RTI
USER_IRQ RTI


;=======================================FDC methods =========================================================================
; these will call code between $2000-2FFF
FDC_OPEN	RTS
FDC_CLOSE	RTS
FDC_DELETE	RTS
FDC_CAT		RTS
FDC_RENAME	RTS
FDC_LOCK	RTS
FDC_UNLOCK	RTS
FDC_INIT	RTS
FDC_VERIFY	RTS
FDC_READ	RTS
FDC_WRITE	RTS

;UART defines
SERIAL_DATA     EQU     $8000           ;8251 Data Address
SERIAL_CMD      EQU     $8001           ;8251 Cmd Address
RST_CMD         EQU     $40             ;Reset Command sent 4 times
MODE_CMD        EQU     %01001101       ;Async mode, 8,n,1, 1x rate
DATA_CMD        EQU     %00110111       ;%00110111 RTS/CTS on or %00010101 RTS/CTS off
RX_READY        EQU     $02             ;8251 ready to recive

;UART Ini
UARTINI PHA						 ;Save accumulator to stack
        LDA     #$00             ;Start with a reset
        STA     SERIAL_CMD
        STA     SERIAL_CMD
        STA     SERIAL_CMD
        LDA     #RST_CMD         ;Should be able to reset device here
        STA     SERIAL_CMD
        LDA     #MODE_CMD    
        STA     SERIAL_CMD      
        LDA     #DATA_CMD
        STA     SERIAL_CMD 
		PLA						;restore accumulator
		RTS						;return to caller
;UART Send Char
;UART Send String
;UART Rec  Char
;=================================== GET_CH ==========================================================================
; GET_CHar gets a single char from the input buffer, result in accumulator 
GET_CH	PHP			;Save Processor			;Stored nomally during call, but not for jmp.
		TXA			;Save X
		PHA			;
		TYA			;Save Y
		PHA
		;GET_CH code, key_buff_b points to current location
		;Store key_buff_b in x
		;Store key_buff_b location in y
		;inc y
		;compare y > key_buff_s
		;break to Zero buffer locations
		;exchage y > accumulator
		;Restore registers
		PLA			;Restore y
		TAY
		PLA			;Restore X
		TAX
		PLP
		RTS
;================================== PUT_CHAR ============================================================================
;PUT_CHar places a char onto the output buffer
PUT_CH	PHP			;Save Processor			;Stored nomally during call, but not for jmp.
		TXA			;Save X
		PHA			;
		TYA			;Save Y
		PHA
		;PUT_CH code, key_buff_b points to current location
		;Store key_buff_b in x
		;Store key_buff_b location in y
		;inc y
		;compare y > key_buff_s
		;break to Zero buffer locations
		;exchage y > accumulator
		;Restore registers
		PLA			;Restore y
		TAY
		PLA			;Restore X
		TAX
		PLP
		RTS
	
;Floppy Defines
;Floppy init 


ORG	$FE00
RESET	CLD				;Clear decimal arithmetic mode
		SEI				;Set interupt disable flag
		LDX	#$FF		;Setup stack
		TXS
		CALL UARTINI	;setup uart

;-------------------------------------------------------------------------
;  Vector area
;-------------------------------------------------------------------------
ORG     $FFF7
USER_VEC        DW     USER_IRQ         ;Unused, what a pity (WOZ is refering to User Interrupt)
ORG     $FFFA
NMI_VEC         DW     NMI_IRQ           ;NMI vector
ORG     $FFFC
RESET_VEC       DW     RESET           ;RESET vector
ORG     $FFFE
IRQ_VEC         DW     IDLE_IRQ          ;IRQ vector

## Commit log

2021-05-20 Update of project
    [6502-Controller.sch, 6502.1.1.kicad_pcb, ResetCircuit.kicad_pcb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]
2021-05-22 Update of PCB
    Updating PCB to newest version, fixing no power light, reset circuit, 8251a reset addition and incorrect 74HC4060 pin out corrections.
    Changed address of 8251a from 0xC000 to 0x8000 on PCB.
    [6502-Controller.kicad_pcb, 6502-Controller.sch]
2021-05-22 Update README.md
    Update of read me to reflect changes to PCB and Schematic.
2021-05-22 Added current version of the monitor
2021-06-06 6502 project update
    Added Gerber's, PCB and updated schematic with single step (not on PCB)
    [6502-Controller v1.1.sch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]
2021-08-14 Fixed R2 issue
    Fixed issue with R2 not having a connection to 5V rail
    [6502-Controller.kicad_pcb, 6502-Controller.sch]
2021-08-14 Update 6502mon.asm
    Changed 8521a uart initalisation, 1x frequency not 64x frequency
2021-08-14 Version 2 silkscreen
    Update of silkscreen to indicate version2
    [6502-Controller.kicad_pcb]
2021-08-26 Update
    Added Backplane schematics, not suitable for production yet.
    Added Comments in controller schematic for memory mappings.
    FDC and Graphics options on the cards.
    [6502-Controller v1.1.sch, BackPlane.kicad_pcb, BackPlane.sch]
2021-09-05 Update For 6502 Controller
    Added Notes to Schematic for Baud rate Generator.
    Added source for New Kernel
    Changed 6502monV1.1.asm baud rate clock to x1 (should be x64)
    [6502-Controller v1.1.sch, BackPlane.sch]
2021-09-05 update
    Working? wozmon.a65.bin added
    [6502-Controller.kicad_pcb]
2022-09-30 Update
    Update of Projects
    [6502-Controller v1.1.sch, 6502-Controller.kicad_pcb, 6502-Controller.sch]
2022-09-30 Update
    Added FDC prototypes and VIA test code
2022-10-01 Update
    Back plane - adding inverters and control signal buffers to schematic, working on pcb for back plane.
    6502.mon - added revised memory locations for devices
    [6502-Controller v1.1.sch, BackPlane.kicad_pcb, BackPlane.sch]
2022-10-01 Update
    Laying out tracks
    [BackPlane.kicad_pcb, BackPlane.sch]
2022-10-12 Update
    Added monEXT.asm ( use this one for A6502 board )
    [ACI.sch]
2022-10-25 update
    Changed 74LS373 to 74LS573, added pull up resistors to input lines
    [BackPlane.kicad_pcb, BackPlane.sch]
2022-11-03 update added basic module
    issue with 74LS245, unit need's to be selected when the ROM and RAM are selected during clock 2.
    [BasicModule.kicad_pcb, BasicModule.sch]
